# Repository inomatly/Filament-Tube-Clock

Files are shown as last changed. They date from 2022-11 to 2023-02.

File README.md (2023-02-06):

# Filament-Tube-Clock
Filament Tube Clock. Developing with microPython or C.2022/10~

## 手順

1. 時計を作る
   1. 構造を調べてデータに起こす
   2. 再加工可能な状態でケースを設計する
   3. ケースを作成する
2. wifiモジュールをテストする
3. マイコンのテストをする。(同じピン配置の方がいいため)
4. 作り変える。

まずはmicroPythonで作成します。その後，Cで書き直す可能性があります。

## 回路

watch.pdfを参照。
基板データは非公開。

なお，フィラメント菅部分は「7セグみたいなものだから」と適当に書きました。雰囲気で読んでください。

## 加工

[onshape](https://cad.onshape.com/documents/2ef8b39e419f2c465de1c02f/w/79a8761cf37ad37e1899c9b7/e/8a61e6004c59a43205288173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)

## 部品

|NAME|Quantity|memo|URL|
|----|---|----|---|
|Raspberry Pi Pico|1||https://akizukidenshi.com/catalog/g/gM-16132/|
|IV-9 |6|フィラメント菅|https://nixie-tube.com/shop/1_76.html|
|5V2A|1|1Aで十分|https://akizukidenshi.com/catalog/g/gM-01801/|
|DCジャック|1|2.1mm|https://akizukidenshi.com/catalog/g/gC-09408/|
|タクトスイッチ|4|色は何でも|https://akizukidenshi.com/catalog/g/gP-03647/|
|M3ねじ||||
|配線用リール||||
|ボタン電池|1|1.5V|https://www.amazon.co.jp/dp/B003X5WJR6?tag=amz-mkt-edg-jp-22|
|電池ホルダ(LR44用)|1||https://akizukidenshi.com/catalog/g/gP-08208/|
|ICソケット18pin|1||https://akizukidenshi.com/catalog/g/gP-00008/|
|ICソケット8pin|1||https://akizukidenshi.com/catalog/g/gP-00017/|
|ICソケット28pin|3||https://akizukidenshi.com/catalog/g/gP-00013/|
|||||
|DS1307+|1|RTC(タイムキーパー)|https://akizukidenshi.com/catalog/g/gI-06949/|
|MCP23017|3|I/Oエキスパンダー|https://akizukidenshi.com/catalog/g/gI-09486/|
|水晶発振子32.768kHz|1||https://akizukidenshi.com/catalog/g/gP-04005/|
|10kΩ|5||https://akizukidenshi.com/catalog/g/gR-25103/|
|1kΩ|2|I2Cバス用|https://akizukidenshi.com/catalog/g/gR-25102/|
|15Ω|6||https://akizukidenshi.com/catalog/g/gR-09429/|
|0.1µF|6||https://akizukidenshi.com/catalog/g/gP-00090/|
|ＧＰＳ受信機キット　１ＰＰＳ出力付き　「みちびき」|1||https://akizukidenshi.com/catalog/g/gK-09991/|

# OSS

本プロジェクトで使用している"ds1307.py"は下記から利用しています。Thank you so much for your excellent work!!

>MicroPython TinyRTC I2C Module, DS1307 RTC + AT24C32N EEPROM
>https://github.com/mcauser/micropython-tinyrtc
>
>MIT License
>Copyright (c) 2018 Mike Causer

# GPSに関して

[ＧＰＳ受信機](https://akizukidenshi.com/catalog/g/gK-09991/)はMiniGPSを使用して設定を下記に変更する。

- baudrate=115200
- GPZDAのみ
- 更新周期はお好みで。5Hzか10Hzくらいでしょうか。

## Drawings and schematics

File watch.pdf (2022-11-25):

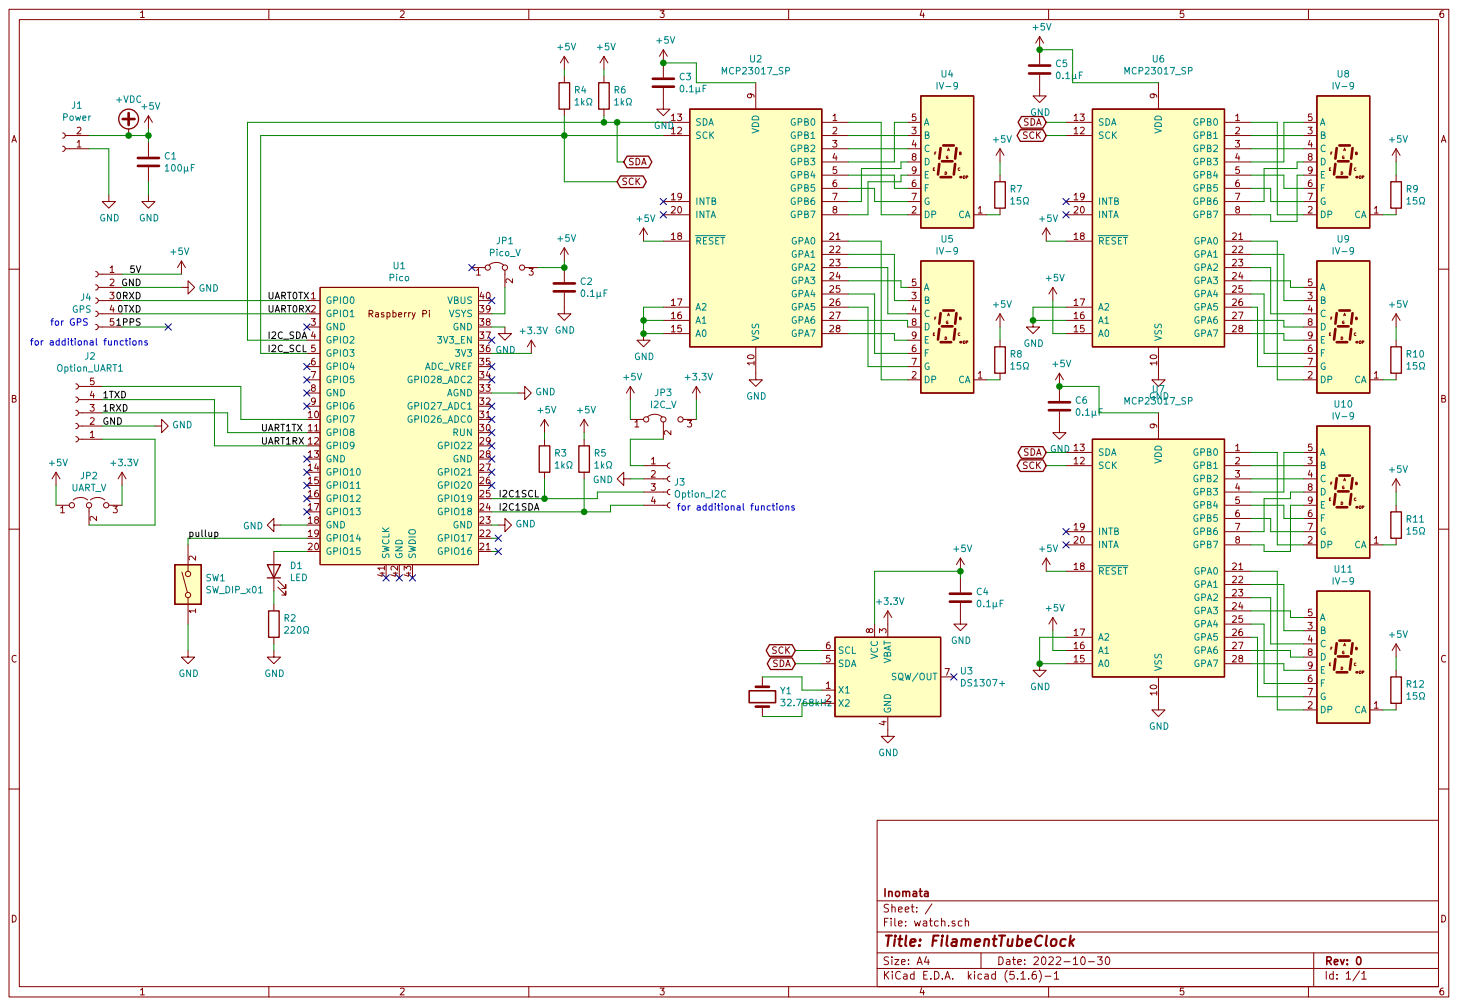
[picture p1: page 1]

4 SDA 5 SCL 6 SQW/OUT 7 VCC

File: watch.sch Sheet: /
Id: 1/1 Title: FilamentTubeClock

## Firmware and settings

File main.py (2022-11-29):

"""
MicroPython, TinyRTC
@tamagogyunyu@gmail.com
"""

from machine import I2C, Pin, RTC, UART, disable_irq, enable_irq
from ds1307 import DS1307
from time import sleep
from params import store_time
#import sys

sleep(5)

#################################################
# 定数
#################################################

ADR_H = 0x22
ADR_M = 0x21
ADR_S = 0x20

NUM_R = 0x13
NUM_L = 0x12

DIR_A = 0x00
DIR_B = 0x01

ALL_ZERO = b'\x00'
ALL_ONE = b'\xff'

NUM_ZERO = b'\x21'
NUM_ONE = b'\xf9'
NUM_TWO = b'\x15'
NUM_THREE = b'\x91'
NUM_FOUR = b'\xc9'
NUM_FIVE = b'\x83'
NUM_SIX = b'\x0b'
NUM_SEVEN = b'\xe1'
NUM_EIGHT = b'\x01'
NUM_NINE = b'\xc1'
NUM_DOT = b'\xfe'

#################################################
#関数宣言
#################################################

#################################################
# ディスプレイの設定
# input: I2Cオブジェクト(RTC)
# output: なし
#################################################

def display_init(d):
    d.writeto_mem(ADR_H,DIR_A,b'\x00')
    d.writeto_mem(ADR_H,DIR_B,b'\x00')
    d.writeto_mem(ADR_M,DIR_A,b'\x00')
    d.writeto_mem(ADR_M,DIR_B,b'\x00')
    d.writeto_mem(ADR_S,DIR_A,b'\x00')
    d.writeto_mem(ADR_S,DIR_B,b'\x00')
    return 0

#################################################
# ディスプレイをオフ
# input: I2Cオブジェクト(RTC)
# output: なし
#################################################
def display_off(d):
    d.writeto_mem(ADR_H,NUM_L,ALL_ONE)
    d.writeto_mem(ADR_H,NUM_R,ALL_ONE)
    d.writeto_mem(ADR_M,NUM_L,ALL_ONE)
    d.writeto_mem(ADR_M,NUM_R,ALL_ONE)
    d.writeto_mem(ADR_S,NUM_L,ALL_ONE)
    d.writeto_mem(ADR_S,NUM_R,ALL_ONE)
    return 0

#################################################
# test用の関数
# input: I2Cオブジェクト(RTC)
# output: なし
#################################################
def display_test_a(d):
    d.writeto_mem(ADR_H,NUM_L,NUM_ONE)
    d.writeto_mem(ADR_H,NUM_R,NUM_TWO)
    d.writeto_mem(ADR_M,NUM_L,NUM_THREE)
    d.writeto_mem(ADR_M,NUM_R,NUM_FOUR)
    d.writeto_mem(ADR_S,NUM_L,NUM_FIVE)
    d.writeto_mem(ADR_S,NUM_R,NUM_SIX)
    return 0

#################################################
# input:hexでもdecでも可。pythonの謎。
# output: 10の位を返す
#################################################
def tens_place(num):
    return int(num / 10)

#################################################
# input : hexでもdecでも可。pythonの謎。
# output: 1の位を返す
#################################################
def ones_place(num):
    return int(num % 10)

#################################################
# input : ascii code。0~9。
# output: decの0~9
#################################################
def ascii_to_num(ascii):
    if ascii == 48:
        return 0
    elif ascii == 49:
        return 1
    elif ascii == 50:
        return 2
    elif ascii == 51:
        return 3
    elif ascii == 52:
        return 4
    elif ascii == 53:
        return 5
    elif ascii == 54:
        return 6
    elif ascii == 55:
        return 7
    elif ascii == 56:
        return 8
    elif ascii == 57:
        return 9
    else:
        return -1  #一回くらいエラーが来てもOK

#################################################
# input: dec。ただしhexも可
# output: b'\x00'など，バイナリ。
#################################################
def dec_to_displayNum(decnum: int):
    global NUM_ZERO
    global NUM_ONE
    global NUM_TWO
    global NUM_THREE
    global NUM_FOUR
    global NUM_FIVE
    global NUM_SIX
    global NUM_SEVEN
    global NUM_EIGHT
    global NUM_NINE

    if decnum == 1:
        return NUM_ONE
    elif decnum == 2:
        return NUM_TWO
    elif decnum == 3:
        return NUM_THREE 
    elif decnum == 4:
        return NUM_FOUR
    elif decnum == 5:
        return NUM_FIVE
    elif decnum == 6:
        return NUM_SIX
    elif decnum == 7:
        return NUM_SEVEN
    elif decnum == 8:
        return NUM_EIGHT
    elif decnum == 9:
        return NUM_NINE
    elif decnum == 0:
        return NUM_ZERO
    else:
        return 0

#################################################
# input : hexでもdecでも可。pythonの謎。,I2Cオブジェクト(RTC)
# output: ディスプレイに表示
#################################################
def display_out(now: store_time, d):
    d.writeto_mem(ADR_H,NUM_L,dec_to_displayNum(now.hour_L))
    d.writeto_mem(ADR_H,NUM_R,dec_to_displayNum(now.hour_R))
    d.writeto_mem(ADR_M,NUM_L,dec_to_displayNum(now.min_L))
    d.writeto_mem(ADR_M,NUM_R,dec_to_displayNum(now.min_R))
    d.writeto_mem(ADR_S,NUM_L,dec_to_displayNum(now.sec_L))
    d.writeto_mem(ADR_S,NUM_R,dec_to_displayNum(now.sec_R))
    return 0

#################################################
# input : rtcのタプル[7], 更新するインスタンス
# output: store_time 型のインスタンスに値を格納する
#################################################
def update_time(now):
    ts = store_time(0,0,0,0,0,0,0)
    ts.hour_L=tens_place(now[4])
    ts.hour_R=ones_place(now[4])
    ts.min_L=tens_place(now[5])
    ts.min_R=ones_place(now[5])
    ts.sec_L=tens_place(now[6])
    ts.sec_R=ones_place(now[6])
    return ts

#################################################
# input : GPSのbyte, rtcオブジェクト
# output: rtcオブジェクト内部のメモリに書き込み
#################################################
def correct_time(buff, rtc_write):
    #print(str(buff)+"type: "+str(type(buff))) 
    year = ascii_to_num(buff[24])*1000+ascii_to_num(buff[25])*100 + ascii_to_num(buff[26])*10 + ascii_to_num(buff[27])
    #print("Y: "+str(year))
    month = ascii_to_num(buff[21])*10 + ascii_to_num(buff[22])
    #print("M: "+str(month))
    date = ascii_to_num(buff[18])*10 + ascii_to_num(buff[19])
    #print("d: "+str(date))
    day = 2
    hour = ascii_to_num(buff[7])*10 + ascii_to_num(buff[8]) + 9
    if hour >25:
        hour = hour-24
    #print("h: "+str(hour))
    mini = ascii_to_num(buff[9])*10 + ascii_to_num(buff[10])
    #print("m: "+str(mini))
    sec = ascii_to_num(buff[11])*10 + ascii_to_num(buff[12])
    mic = ascii_to_num(buff[14])
    #print("s: "+str(sec)+"."+str(mic))
    rtc=(year,month,date,day,hour,mini, sec,mic)
    print("rtc: "+str(rtc))
    rtc_write.datetime(rtc)
    return 0

#################################################
# gpsからデータを受信。
# input : GPS(UARTオブジェクト)
# output: GPSからのデータ byte
#################################################
def read_gps(gps):
    i = 0
    while i < 2:
        if gps.any() > 26:
            buffer = gps.read()
            i = i+1
            #print("hour"+str(ascii_to_num(buffer[7])*10 + ascii_to_num(buffer[8])))
            if ((ascii_to_num(buffer[7])*10 + ascii_to_num(buffer[8]))>24)or((ascii_to_num(buffer[7])*10 + ascii_to_num(buffer[8]))<0):
                i=0
    return buffer
#################################################
# 割り込み
#################################################
def callback(pin):
    global ledRed
    global uart
    global ds_rtc
    ledRed.high()
    i=0
    b= read_gps(uart)
    correct_time(b,ds_rtc) #後で変更
    ledRed.low()
    return 0

#################################################
# configuration
#################################################
led25 = Pin(25, Pin.OUT)
ledRed = Pin(15, Pin.OUT, Pin.PULL_UP)

sw = Pin(14, Pin.IN, Pin.PULL_UP)
sw.irq(trigger=Pin.IRQ_FALLING, handler=callback)

i2c = I2C(1,scl = Pin(3),sda = Pin(2), freq=100000)
ds_rtc = DS1307(i2c)
sleep(1)
uart = UART(0, baudrate=115200, tx=Pin(0), rx=Pin(1))#GPS
#state = disable_irq()

#################################################
# main関数
#################################################
def main():
    global led25
    global ledRed
    global sw
    global i2c
    global ds_rtc

    # 変数定義
    time_s = store_time(0,0,0,0,0,0,0) #h,h,m,m,s,s,f
    # 初期化処理
    led25.high()
    ledRed.high()
    display_init(i2c)
    display_off(i2c)

    buf=read_gps(uart)
    correct_time(buf,ds_rtc)

    sleep(1)
    print("#"+str(ds_rtc.datetime()))
    ledRed.low()

    while (1):
        #enable_irq(state)
        rtc_now = ds_rtc.datetime()
        time_s = update_time(rtc_now) #rtcから構造体にデータ取得
        display_out(time_s,i2c)
        sleep(0.5)
        if ((time_s.hour_L==1 and time_s.hour_R==1 and time_s.min_L == 5 and time_s.min_R == 9 and time_s.sec_L == 5 and time_s.sec_R >= 9) or (time_s.hour_L==1 and time_s.hour_R==2 and time_s.min_L == 0 and time_s.min_R == 0 and time_s.sec_L == 0 and time_s.sec_R < 1) ):
            led25.high()
            buf=read_gps(uart)
            correct_time(buf,ds_rtc)
            led25.low()
    print("stop")

if __name__ == '__main__':
    main()

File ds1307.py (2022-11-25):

"""
MicroPython TinyRTC I2C Module, DS1307 RTC + AT24C32N EEPROM
https://github.com/mcauser/micropython-tinyrtc

MIT License
Copyright (c) 2018 Mike Causer

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
BCD Format:
https://en.wikipedia.org/wiki/Binary-coded_decimal
"""

from micropython import const

DATETIME_REG = const(0) # 0x00-0x06
CHIP_HALT    = const(128)
CONTROL_REG  = const(7) # 0x07
RAM_REG      = const(8) # 0x08-0x3F

class DS1307(object):
    """Driver for the DS1307 RTC."""
    def __init__(self, i2c, addr=0x68):
        self.i2c = i2c
        self.addr = addr
        self.weekday_start = 1
        self._halt = False

    def _dec2bcd(self, value):
        """Convert decimal to binary coded decimal (BCD) format"""
        return (value // 10) << 4 | (value % 10)

    def _bcd2dec(self, value):
        """Convert binary coded decimal (BCD) format to decimal"""
        return ((value >> 4) * 10) + (value & 0x0F)

    def datetime(self, datetime=None):
        """Get or set datetime"""
        if datetime is None:
            buf = self.i2c.readfrom_mem(self.addr, DATETIME_REG, 7)
            return (
                self._bcd2dec(buf[6]) + 2000, # year
                self._bcd2dec(buf[5]), # month
                self._bcd2dec(buf[4]), # day
                self._bcd2dec(buf[3] - self.weekday_start), # weekday
                self._bcd2dec(buf[2]), # hour
                self._bcd2dec(buf[1]), # minute
                self._bcd2dec(buf[0] & 0x7F), # second
                0 # subseconds
            )
        buf = bytearray(7)
        buf[0] = self._dec2bcd(datetime[6]) & 0x7F # second, msb = CH, 1=halt, 0=go
        buf[1] = self._dec2bcd(datetime[5]) # minute
        buf[2] = self._dec2bcd(datetime[4]) # hour
        buf[3] = self._dec2bcd(datetime[3] + self.weekday_start) # weekday
        buf[4] = self._dec2bcd(datetime[2]) # day
        buf[5] = self._dec2bcd(datetime[1]) # month
        buf[6] = self._dec2bcd(datetime[0] - 2000) # year
        if (self._halt):
            buf[0] |= (1 << 7)
        self.i2c.writeto_mem(self.addr, DATETIME_REG, buf)

    def halt(self, val=None):
        """Power up, power down or check status"""
        if val is None:
            return self._halt
        reg = self.i2c.readfrom_mem(self.addr, DATETIME_REG, 1)[0]
        if val:
            reg |= CHIP_HALT
        else:
            reg &= ~CHIP_HALT
        self._halt = bool(val)
        self.i2c.writeto_mem(self.addr, DATETIME_REG, bytearray([reg]))

    def square_wave(self, sqw=0, out=0):
        """Output square wave on pin SQ at 1Hz, 4.096kHz, 8.192kHz or 32.768kHz,
        or disable the oscillator and output logic level high/low."""
        rs0 = 1 if sqw == 4 or sqw == 32 else 0
        rs1 = 1 if sqw == 8 or sqw == 32 else 0
        out = 1 if out > 0 else 0
        sqw = 1 if sqw > 0 else 0
        reg = rs0 | rs1 << 1 | sqw << 4 | out << 7
        self.i2c.writeto_mem(self.addr, CONTROL_REG, bytearray([reg]))

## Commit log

2022-11-25 make read_gps function and fix a problem
    [main.py]
2022-11-29 fix baudrate and add self-calibration
    [main.py]
2023-02-06 fix readme.md and add PCB data
    [watch-B_Cu.gbl, watch-B_Mask.gbs, watch-Edge_Cuts.gm1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]
